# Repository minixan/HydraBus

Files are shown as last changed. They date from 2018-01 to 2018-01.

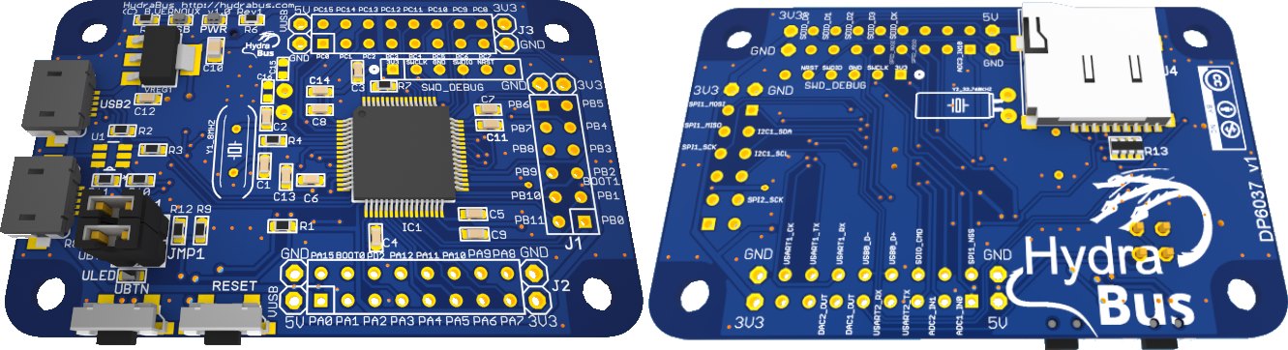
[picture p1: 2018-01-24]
HydraBus_board.jpg

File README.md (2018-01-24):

HydraBus Schematic and Board
========

The HydraBus is an open source multi-tool hardware for anyone interested in Learning/Developping/Debugging/Hacking/Penetration Testing for basic or advanced embedded hardware.

The MCU is one of the fastest Cortex M4F on the market and is more than 40X faster than an Arduino (STM32F415, 32bits@168MHz=210DMIPS vs Arduino Uno, 8bits@16MHz=5.2DMIPS).

HydraBus can be also used as Test Bench for hardware validation/test with help of embedded python script or native C/C++ firmware and it is a perfect tool for hardware pentesting.

HydraBus is evolutive with the help of “Shield” hardware extensions (first Shield is HydraNFC).

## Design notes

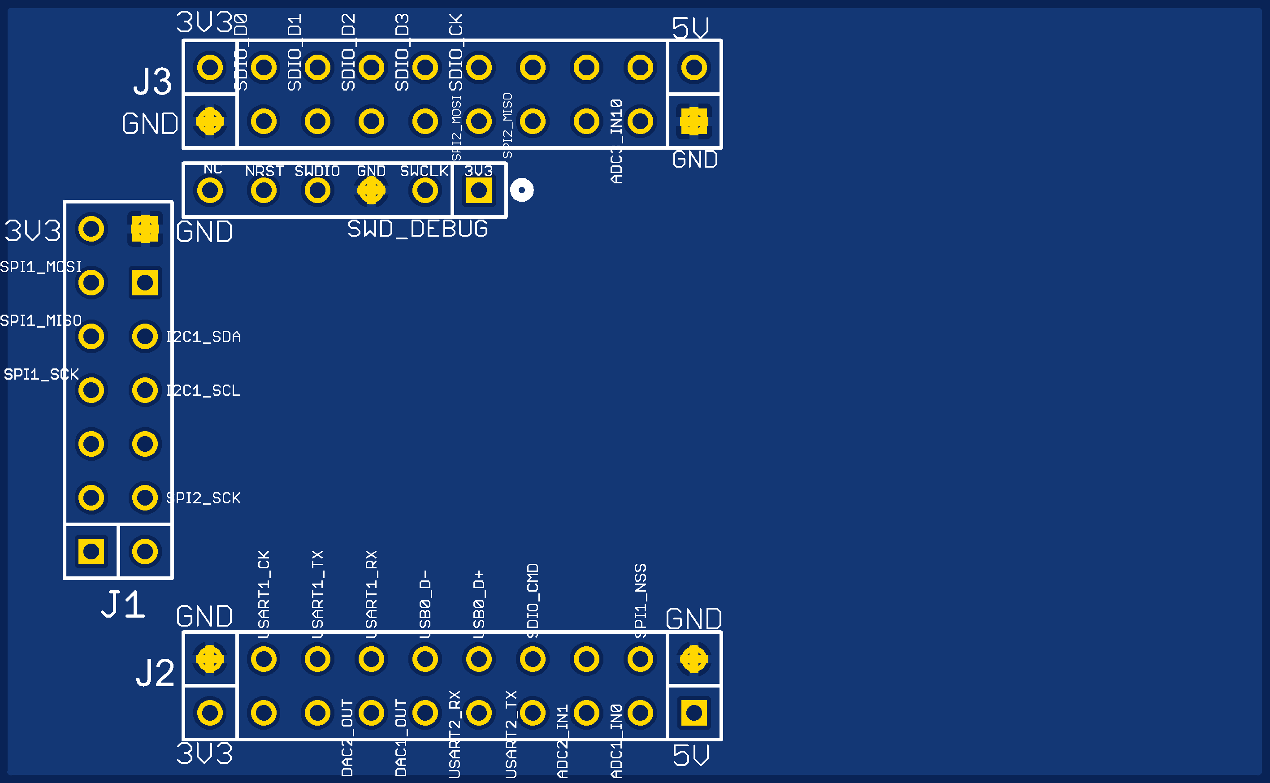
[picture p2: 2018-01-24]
HydraBus_1_0_Template/HydraBus_1_0_Template_board_bottom.png

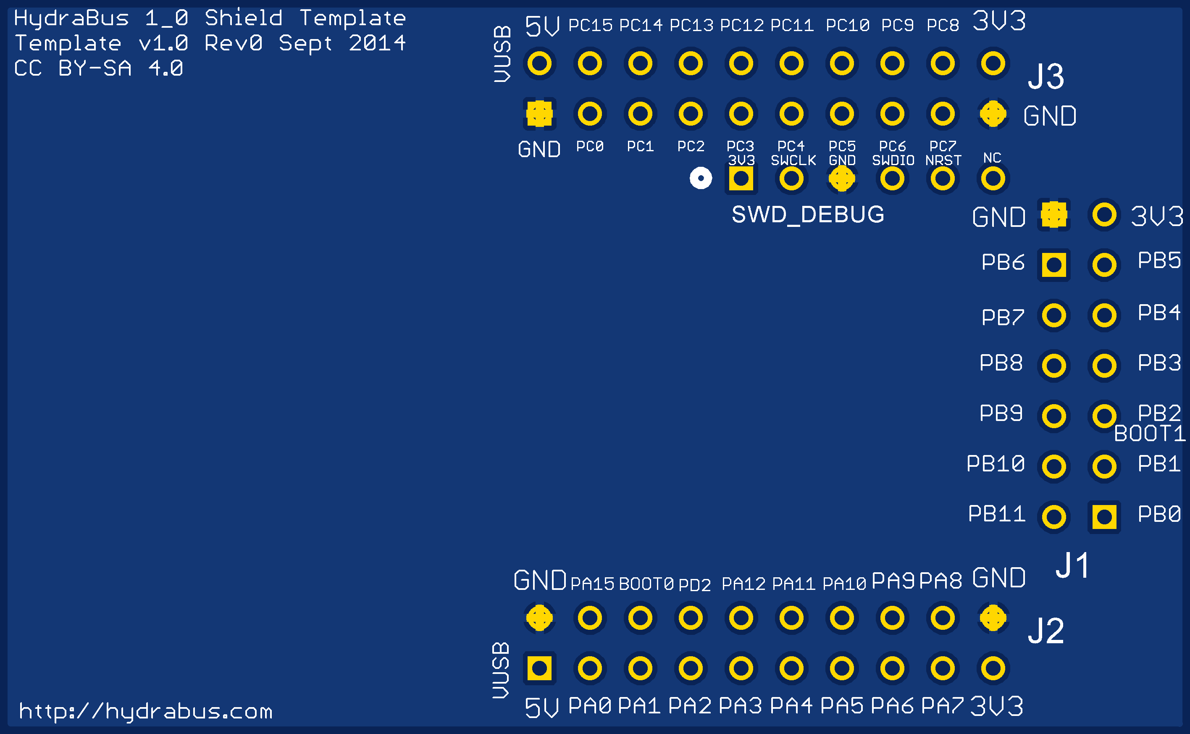
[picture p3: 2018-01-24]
HydraBus_1_0_Template/HydraBus_1_0_Template_board_top.png

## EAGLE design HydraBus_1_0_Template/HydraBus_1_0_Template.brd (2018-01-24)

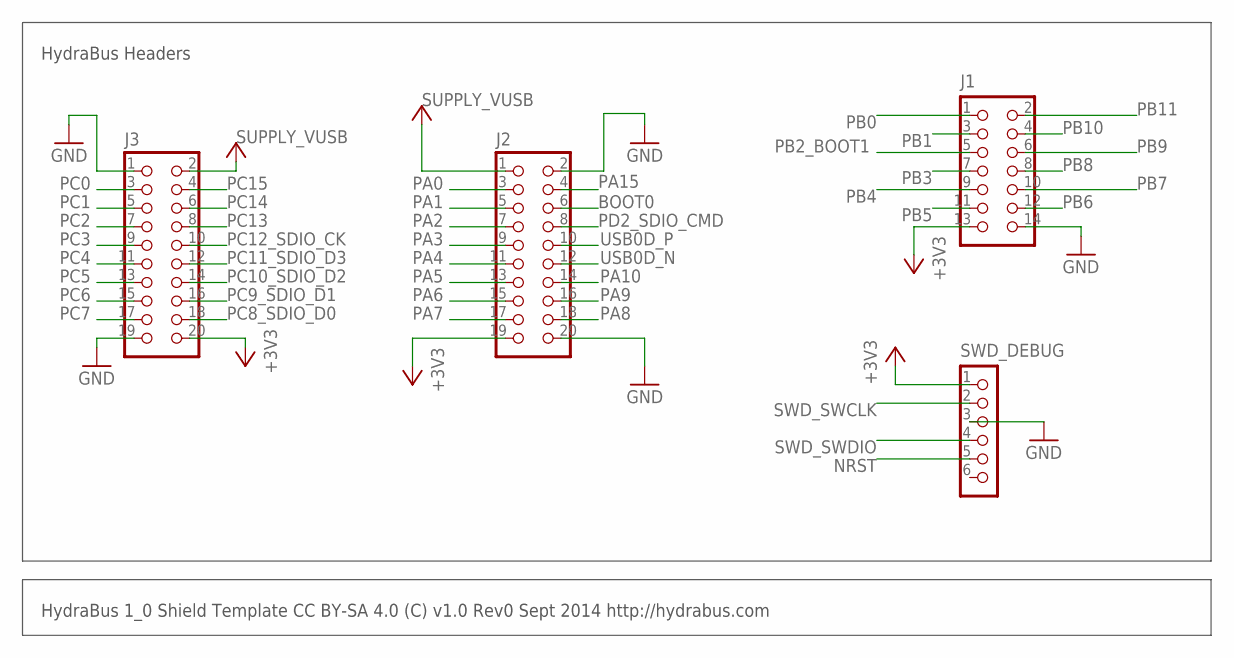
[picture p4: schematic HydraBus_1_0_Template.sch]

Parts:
J1: HYDRABUS_SHIELD_CON_HEADER_2X07; HYDRABUS_SHIELD_M2X7
J2, J3: HYDRABUS_SHIELD_CON_HEADER_2X10; HYDRABUS_SHIELD_M2X10
SWD_DEBUG: HYDRABUS_SHIELD_CON_HEADER_1X06; HYDRABUS_SHIELD_M1X6

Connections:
+3V3: J1.13, J2.19, J3.20, SWD_DEBUG.1
BOOT0: J2.6
GND: J1.14, J2.2, J2.20, J3.1, J3.19, SWD_DEBUG.3
NRST: SWD_DEBUG.5
PA0: J2.3
PA1: J2.5
PA2: J2.7
PA3: J2.9
PA4: J2.11
PA5: J2.13
PA6: J2.15
PA7: J2.17
PA8: J2.18
PA9: J2.16
PA10: J2.14
PA15: J2.4
PB0: J1.1
PB1: J1.3
PB2_BOOT1: J1.5
PB3: J1.7
PB4: J1.9
PB5: J1.11
PB6: J1.12
PB7: J1.10
PB8: J1.8
PB9: J1.6
PB10: J1.4
PB11: J1.2
PC0: J3.3
PC1: J3.5
PC2: J3.7
PC3: J3.9
PC4: J3.11
PC5: J3.13
PC6: J3.15
PC7: J3.17
PC8_SDIO_D0: J3.18
PC9_SDIO_D1: J3.16
PC10_SDIO_D2: J3.14
PC11_SDIO_D3: J3.12
PC12_SDIO_CK: J3.10
PC13: J3.8
PC14: J3.6
PC15: J3.4
PD2_SDIO_CMD: J2.8
SWD_SWCLK: SWD_DEBUG.2
SWD_SWDIO: SWD_DEBUG.4
USB0D_N: J2.12
USB0D_P: J2.10
VUSB: J2.1, J3.2

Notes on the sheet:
HydraBus 1_0 Shield Template CC BY-SA 4.0 (C) v1.0 Rev0 Sept 2014 http://hydrabus.com
HydraBus Headers

Board: 2 copper layers, 4 parts (0 on the bottom side), 3 nets, no tracks yet.

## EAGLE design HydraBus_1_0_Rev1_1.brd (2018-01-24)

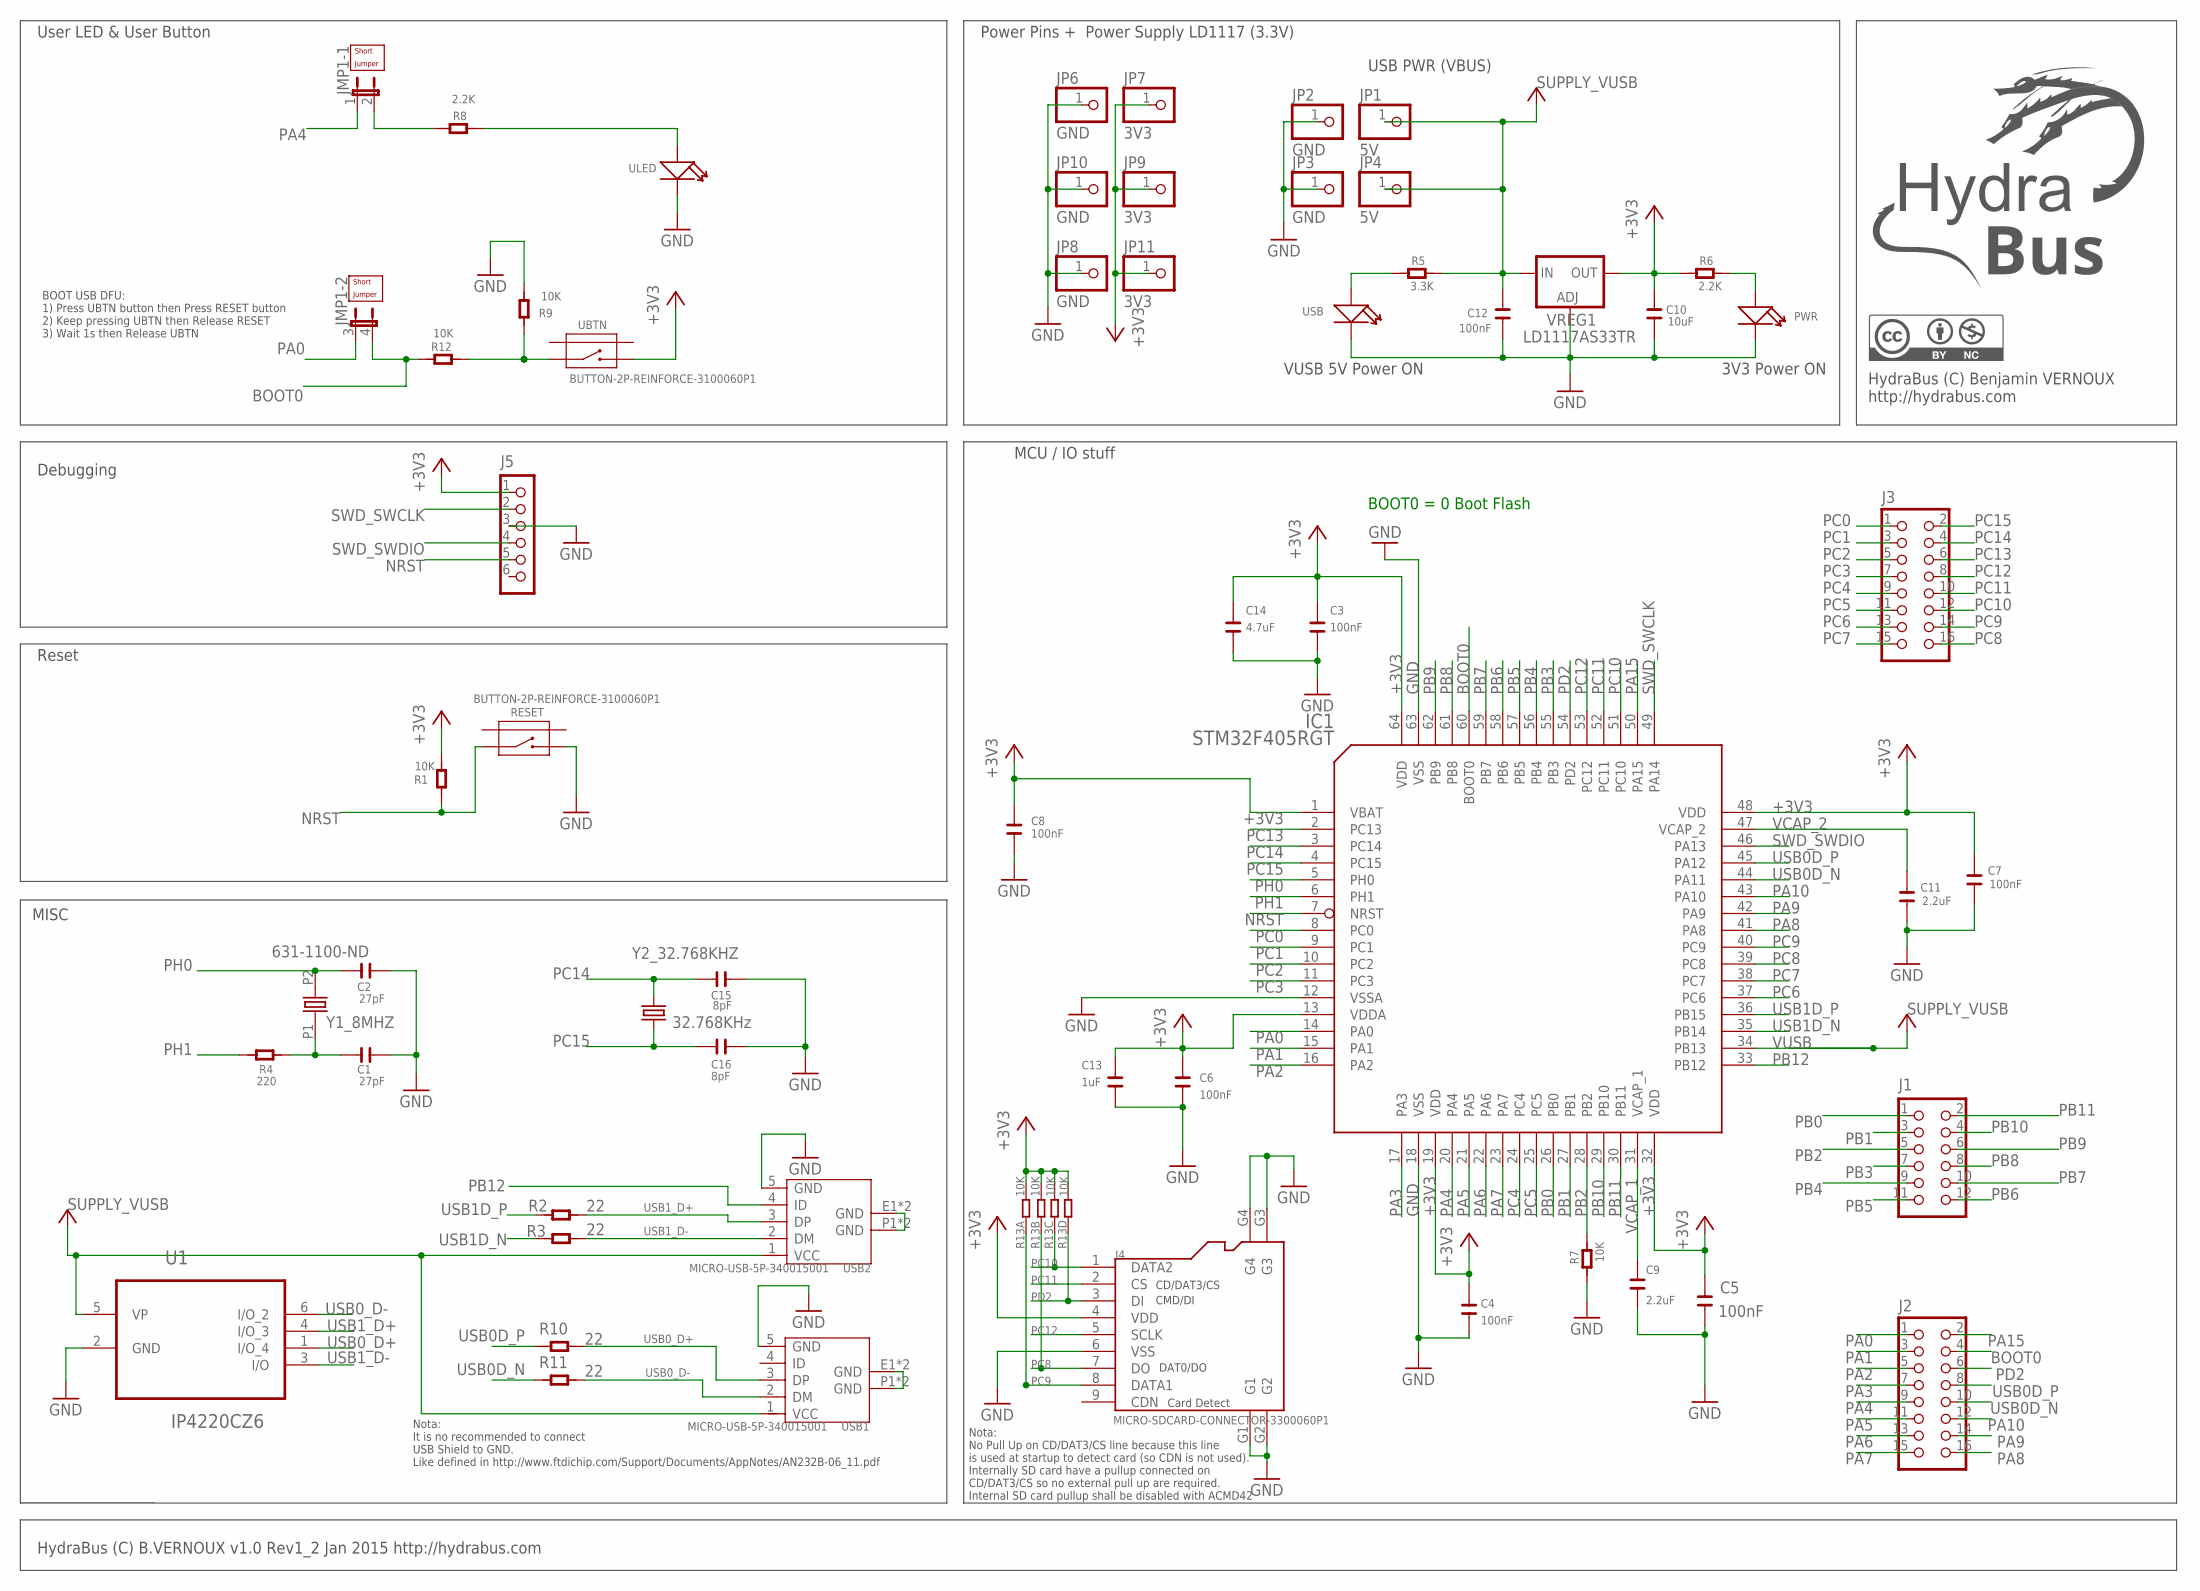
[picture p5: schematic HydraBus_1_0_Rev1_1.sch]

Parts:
C1, C2: 27pF; C0603
C3, C4, C5, C6, C7, C8, C12: 100nF; C0603
C9, C11: 2.2uF; C0603
C10: 10uF; C0805
C13: 1uF; C0603
C14: 4.7uF; C0603
C15, C16: 8pF; C0603
IC1: STM32F405RGT; LQFP64
J1: CON_HEADER_2X06; M2X6
J2, J3: CON_HEADER_2X08; M2X8
J4: MICRO-SDCARD-CONNECTOR-3300060P1; 9P-SMD-W-RING
J5: CON_HEADER_1X06-PTH; M1X6
JMP1: JP2QE; JP2Q
JMP_UBTN: SHORT-JUMPER-2P-3460440P1; 2P-2.54
JMP_ULED: SHORT-JUMPER-2P-3460440P1; 2P-2.54
JP1, JP4: 5V; 1X01
JP2, JP3, JP6, JP8, JP10: GND; 1X01
JP7, JP9, JP11: 3V3; 1X01
PWR: LED; LED0603
R1, R7, R9, R12: 10K; R0603
R2, R3, R10, R11: 22; R0603
R4: 220; R0603
R5: 3.3K; R0603
R6, R8: 2.2K; R0603
R13: 10K; R1206-8
RESET: BUTTON-2P-REINFORCE-3100060P1; 4P-SMD-7.0X3.5X3.5H-90D
U1: IP4220CZ6; SOT95P275X110-6N
UBTN: BUTTON-2P-REINFORCE-3100060P1; 4P-SMD-7.0X3.5X3.5H-90D
ULED: LED; LED0603
USB: LED; LED0603
USB1, USB2: MICRO-USB-5P-340015001; B-SMD-5P
VREG1: LD1117AS33TR; SOT223
Y1_8MHZ: 631-1100-ND; HC-49U-PTH
Y2_32.768KHZ: 32.768KHz; TC38H

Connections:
+3V3: C3.1, C4.1, C5.2, C6.1, C7.1, C8.1, C10.1, C13.1, C14.1, IC1.1 (VBAT), IC1.13 (VDDA), IC1.19 (VDD), IC1.32 (VDD), IC1.48 (VDD), IC1.64 (VDD), J4.4 (VDD), J5.1, JP7.1, JP9.1, JP11.1, R1.2, R6.2, R13.5 (2), R13.6 (2), R13.7 (2), R13.8 (2), UBTN.2, VREG1.4 (OUT)
BOOT0: IC1.60 (BOOT0), J2.4, JMP1.4 (2), R12.2
GND: C1.2, C2.2, C3.2, C4.2, C5.1, C6.2, C7.2, C8.2, C9.1, C10.2, C11.2, C12.2, C13.2, C14.2, C15.2, C16.2, IC1.12 (VSSA), IC1.18 (VSS), IC1.63 (VSS), J4.6 (VSS), J4.G1, J4.G2, J4.G3, J4.G4, J5.3, JP2.1, JP3.1, JP6.1, JP8.1, JP10.1, PWR.-, R7.2, R9.2, RESET.2, U1.2 (GND), ULED.-, USB.-, USB1.5 (GND), USB2.5 (GND), VREG1.1 (ADJ)
unnamed: C1.1, R4.1, Y1_8MHZ.P1 (1)
unnamed: JMP1.2, R8.2
unnamed: R9.1, R12.1, UBTN.1
unnamed: R8.1, ULED.+
unnamed: USB2.E1 (GND), USB2.E2 (GND), USB2.P1 (GND), USB2.P2 (GND)
unnamed: USB1.E1 (GND), USB1.E2 (GND), USB1.P1 (GND), USB1.P2 (GND)
unnamed: R5.2, USB.+
unnamed: PWR.+, R6.1
NRST: IC1.7 (NRST), J5.5, R1.1, RESET.1
PA0: IC1.14 (PA0), J2.1, JMP1.3 (1)
PA1: IC1.15 (PA1), J2.3
PA2: IC1.16 (PA2), J2.5
PA3: IC1.17 (PA3), J2.7
PA4: IC1.20 (PA4), J2.9, JMP1.1
PA5: IC1.21 (PA5), J2.11
PA6: IC1.22 (PA6), J2.13
PA7: IC1.23 (PA7), J2.15
PA8: IC1.41 (PA8), J2.16
PA9: IC1.42 (PA9), J2.14
PA10: IC1.43 (PA10), J2.12
PA15: IC1.50 (PA15), J2.2
PB0: IC1.26 (PB0), J1.1
PB1: IC1.27 (PB1), J1.3
PB2: IC1.28 (PB2), J1.5, R7.1
PB3: IC1.55 (PB3), J1.7
PB4: IC1.56 (PB4), J1.9
PB5: IC1.57 (PB5), J1.11
PB6: IC1.58 (PB6), J1.12
PB7: IC1.59 (PB7), J1.10
PB8: IC1.61 (PB8), J1.8
PB9: IC1.62 (PB9), J1.6
PB10: IC1.29 (PB10), J1.4
PB11: IC1.30 (PB11), J1.2
PB12: IC1.33 (PB12), USB2.4 (ID)
PC0: IC1.8 (PC0), J3.1
PC1: IC1.9 (PC1), J3.3
PC2: IC1.10 (PC2), J3.5
PC3: IC1.11 (PC3), J3.7
PC4: IC1.24 (PC4), J3.9
PC5: IC1.25 (PC5), J3.11
PC6: IC1.37 (PC6), J3.13
PC7: IC1.38 (PC7), J3.15
PC8: IC1.39 (PC8), J3.16, J4.7 (DO), R13.2 (1)
PC9: IC1.40 (PC9), J3.14, J4.8 (DATA1), R13.1
PC10: IC1.51 (PC10), J3.12, J4.1 (DATA2), R13.3 (1)
PC11: IC1.52 (PC11), J3.10, J4.2 (CS)
PC12: IC1.53 (PC12), J3.8, J4.5 (SCLK)
PC13: IC1.2 (PC13), J3.6
PC14: C15.1, IC1.3 (PC14), J3.4, Y2_32.768KHZ.2
PC15: C16.1, IC1.4 (PC15), J3.2, Y2_32.768KHZ.1
PD2: IC1.54 (PD2), J2.6, J4.3 (DI), R13.4 (1)
PH0: C2.1, IC1.5 (PH0), Y1_8MHZ.P2 (2)
PH1: IC1.6 (PH1), R4.2
SWD_SWCLK: IC1.49 (PA14), J5.2
SWD_SWDIO: IC1.46 (PA13), J5.4
USB0D_N: IC1.44 (PA11), J2.10, R11.2
USB0D_P: IC1.45 (PA12), J2.8, R10.2
USB0_D+: R10.1, U1.1 (I/O_4), USB1.3 (DP)
USB0_D-: R11.1, U1.6 (I/O_2), USB1.2 (DM)
USB1D_N: IC1.35 (PB14), R3.2
USB1D_P: IC1.36 (PB15), R2.2
USB1_D+: R2.1, U1.4 (I/O_3), USB2.3 (DP)
USB1_D-: R3.1, U1.3 (I/O), USB2.2 (DM)
VCAP_1: C9.2, IC1.31 (VCAP_1)
VCAP_2: C11.1, IC1.47 (VCAP_2)
VUSB: C12.1, IC1.34 (PB13), JP1.1, JP4.1, R5.1, U1.5 (VP), USB1.1 (VCC), USB2.1 (VCC), VREG1.3 (IN)

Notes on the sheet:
Debugging
Power Pins + Power Supply LD1117 (3.3V)
MCU / IO stuff
MISC
Reset
BOOT0 = 0 Boot Flash
USB PWR (VBUS)
3V3 Power ON
VUSB 5V Power ON
HydraBus (C) B.VERNOUX v1.0 Rev1_2 Jan 2015 http://hydrabus.com
User LED & User Button
CD/DAT3/CS
CMD/DI
Card Detect
DAT0/DO
Nota: No Pull Up on CD/DAT3/CS line because this line is used at startup to detect card (so CDN is not used). Internally SD card have a pullup connected on CD/DAT3/CS so no external pull up are required. Internal SD card pullup shall be disabled with ACMD42
HydraBus (C) Benjamin VERNOUX http://hydrabus.com
Nota: It is no recommended to connect USB Shield to GND. Like defined in http://www.ftdichip.com/Support/Documents/AppNotes/AN232B-06_11.pdf
BOOT USB DFU: 1) Press UBTN button then Press RESET button 2) Keep pressing UBTN then Release RESET 3) Wait 1s then Release UBTN

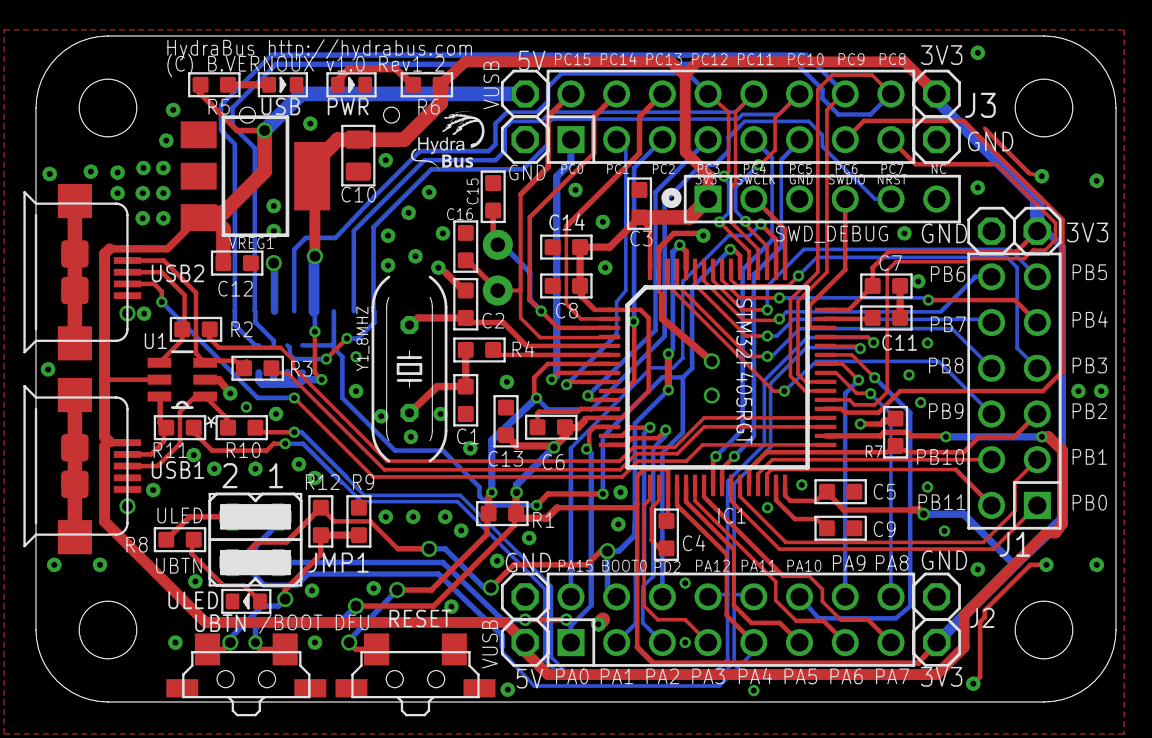
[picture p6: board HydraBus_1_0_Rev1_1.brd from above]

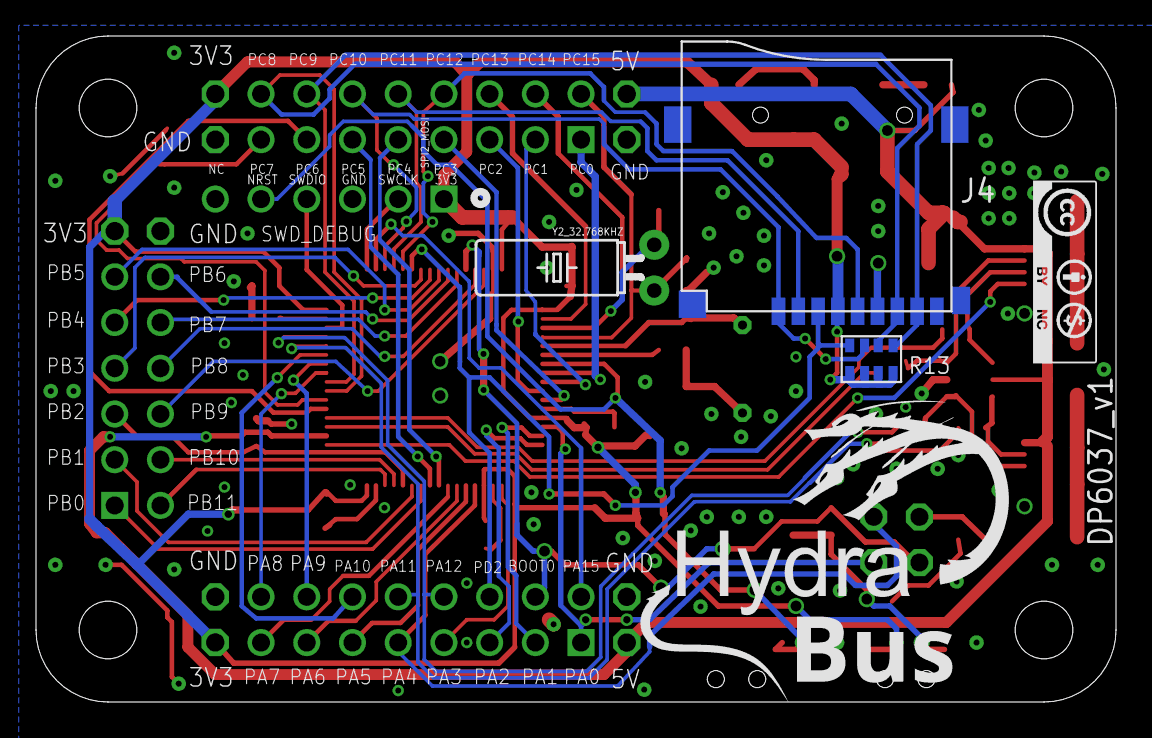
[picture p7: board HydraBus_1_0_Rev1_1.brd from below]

Board: 2 copper layers, 60.0 x 37.0 mm, 60 parts (3 on the bottom side), 69 nets.

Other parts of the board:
U$1: DP6037_V1

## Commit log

2018-01-24 second commit
    [HydraBus_1_0_Rev1_1.brd, HydraBus_1_0_Rev1_1.sch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]
2018-01-24 new commit
    [HydraBus_1_0_Rev1_1.brd, HydraBus_1_0_Rev1_1.sch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]
2018-01-24 Updated .sch and .brd
    [HydraBus_1_0_Rev1_1.brd, HydraBus_1_0_Rev1_1.sch]
2018-01-24 Added hardware folder
    [HydraBus_1_0_Rev1_1.brd, HydraBus_1_0_Rev1_1.sch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]
2018-01-24 Updated hardware folder
    [HydraBus_1_0_Rev1_1.brd, HydraBus_1_0_Rev1_1.sch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]
